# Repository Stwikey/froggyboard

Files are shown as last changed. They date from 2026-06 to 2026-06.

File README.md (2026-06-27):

# Keroppi
Screenshot 2026-06-21 at 12 25 49 AM

A cozy keyboard with every add-on you can think of! Keroppi is a wired keyboard, powered by a Raspberry Pi Pico through a modern USB-C port. It resembles a 75% keyboard layout style with 79 keys and also features a rotary encoder that can be used to toggle many short cuts such as turning the volume up or down. It also acts as another switch! There is also a TFT LCD screen that can display all sorts of images as you type! Finally, Keroppi has per key RGB lighting, and plays cool lighting animations on the keyboard!

# What does Keroppi do?

Keroppi is a wired keyboard that can be connected to your computer so you can start typing comfortably! it comes with cool components such as per-key RGB backlighting that plays animations as you type, a rotary encoder, and a TFT LCD screen that can display cool images or animations! Keroppi was designed to be an "all in one" keyboard, at least it's everything that I would want in a keyboard :D

# Why does Keroppi exist?

I've never owned a keyboard before despite being on my computer all day so I thought this was the perfect time to make one from scratch! Plus I'd be able to add as many features as I want and completely personalize it :D

# How do you use Keroppi?

## Assembly Instructions

#### 1. Handsoldering the PCB

Start by assembling the PCB! Handsolder all of the components onto the the PCB board according to the silkscreen diagram, that includes any LEDs, capacitors, resistors, pin headers, Raspberry Pi Pico, USB-C, TFT LCD, rotary encoder, and hotswap sockets.

The bottom should look something like this

Screenshot 2026-06-26 at 2 46 52 AM

The top should look something like this 

Screenshot 2026-06-26 at 2 46 19 AM

#### 1.5. Soldering the Data Lines

Twist two jumper wires together, trying to keep them the same length. Solder one of the jumper wires from TP2 on the Raspberry Pi Pico to D- and a jumper wire from TP3 on the Raspberry Pi Pico to D+ to connect the data lines.

Please note that although this method can work, it is still risky as data may not be able to establish a reliable connection. If this happens and you see data is not being transferred well, you can simply just use the usb port instead of the usb-c port.

#### 2. Assembling the Switch Plate

Assemble the switch plate by sliding in the stabilizers to their respective mounts

Screenshot 2026-06-22 at 5 50 42 PM

#### 3. Attach the Base

Install M2 female–male hex spacers in the base mounting holes and space out the switch plate from the PCB using 4mm spacers, next screw the layers in using a M2 screws inserted from the switch plate

Screenshot 2026-06-22 at 5 55 56 PM
Screenshot 2026-06-22 at 5 55 36 PM

#### 4. Attach the top plate

Slide in the top plate and it should hold screwless using friction! 

Screenshot 2026-06-22 at 5 57 17 PM

#### 5. Insert the switches

You can now insert the switches through the hotswap sockets

Screenshot 2026-06-22 at 6 00 36 PM

#### 6. Attach the keycaps

Attach the keycaps onto the switches

Screenshot 2026-06-22 at 6 01 44 PM

#### 7. Flashing Firmware

Simply start by putting the Raspberry Pi Pico into bootloader mode by plugging it into a USB port and pressing down the BOOTSEL button, once you see RPI-RPI2 open on your computer, drag the frogboard_default.uf2 file onto it (found in the firmware folder of this github repository) and you are ready to start typing!

Screenshot 2026-06-23 at 5 28 59 PM

# Schematic

## Switch Matrix

Screenshot 2026-06-21 at 12 45 51 AM

## RGB Daisy Chain

Screenshot 2026-06-21 at 12 46 11 AM

## Other Components

Screenshot 2026-06-21 at 1 07 53 AM

# PCB

Screenshot 2026-06-25 at 11 18 47 PM

## 3D Viewer Front

Screenshot 2026-06-25 at 11 19 03 PM

## 3D Viewer Back

Screenshot 2026-06-25 at 11 19 16 PM

# 3D Model

Screenshot 2026-06-21 at 12 53 49 AM

Screenshot 2026-06-21 at 12 56 28 AM

# BOM

|Item |Qty Required|Qty*|Unit Price(CAD)|Total Price(CAD)**|URL |
|---|---|----|---|---|---|
|Keyboard PCB |1 |5 |8.64 |43.18 |https://cart.jlcpcb.com/quote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 |
|SK6812 MINI-E |80 |100 |0.07 |7.25 |https://www.aliexpress.com/item/1005005186515165.html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 |
|Kailh Hot-swappable Sockets |80 |90  |0.23 |21.13 |https://www.aliexpress.com/item/1005002240956679.html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 |
|Gateron Clear Yellow MX Switches |80 |90  |0.4 |36.4 |https://www.aliexpress.com/item/1005006376024657.html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 |
|Green PBT Keycaps Cherry Profile |80 |1 |41.48 |41.48 |https://www.aliexpress.com/item/1005011698106230.html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 |
|Raspberry Pi Pico |1 |1 |9.61 |9.61 |https://www.aliexpress.com/item/1005008488567735.html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|
|Pin Header Kit for Raspberry Pi Pico |1 |1 |4.34 |4.34 |https://www.aliexpress.com/item/1005011890511721.html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 |
|Plate-Mounted Stabilizers (4x2u 1x6.25u)|1 |1 |13.53 |13.53 |https://www.aliexpress.com/item/1005001840872635.html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 |
|Rotary Encoder Knob |1 |1 |3.73 |3.73 |https://www.aliexpress.com/item/1005008610645902.html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 |
|EC11 Rotary Encoder Plum Axis |1 |5 |16.37 |16.37 |https://www.aliexpress.com/item/1005011653314162.html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 |
|0805 SMD Resistor 130Ω |1 |100 |0.1 |9.52 |https://www.aliexpress.com/item/1005011924238866.html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 |
|0.96 ST7735 LCD |1 |1 |11.26 |11.26 |https://www.lcsc.com/product-detail/C18198246.html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 |
|NMOS Transistor SOT-23 |1 |10  |0.86 |8.63 |https://www.aliexpress.com/item/1005009954469992.html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 |
|08.05 SMD Resistor 5.1k |2 |100 |0.1 |9.52 |https://www.aliexpress.com/item/1005011924238866.html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 |
|THT USB-C |1 |1 |10.45 |10.45 |https://www.lcsc.com/cart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 |
|0805 SMD Resistor 500Ω |3 |100 |0.1 |9.52 |https://www.aliexpress.com/item/1005011924238866.html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 |
|THT White 5mm LED |1 |1 |8.47 |8.47 |https://www.digikey.ca/en/products/detail/cree-led/C513A-WSN-CY0Z0231/5120059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 |
|100nF Ceramic Capacitor SMD |80 |100 |0.03 |2.83 |https://www.aliexpress.com/item/1005007175952826.html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 |
|16mm M2 Screws |15 |482 |0.03 |9.65 |https://www.aliexpress.com/item/1005005546734247.html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 |
|4mm M2 Spacer |15 |20  |0.4 |7.94 |https://www.aliexpress.com/item/1005008727558165.html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 |
|M2 x 4mm Standoffs |15 |30  |0.39 |11.68 |https://www.aliexpress.com/item/1005011821593023.html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 |
|Top Plate |1 |1 |0 |0 |3D Printed |
|Bottom Base |1 |1 |0 |0 |3D Printed |
|Switch Plate |1 |1 |0 |0 |3D Printed |
|Jumper Wires |1 |1 |14.91 |14.91 |https://www.aliexpress.com/item/1005006996255957.html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 |
|Total | | | |311.4 | |

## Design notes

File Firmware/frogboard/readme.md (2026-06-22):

# frogboard

firmware for a 80 key wired keyboard with a rotary encoder, tft lcd, and per key rgb backlighting

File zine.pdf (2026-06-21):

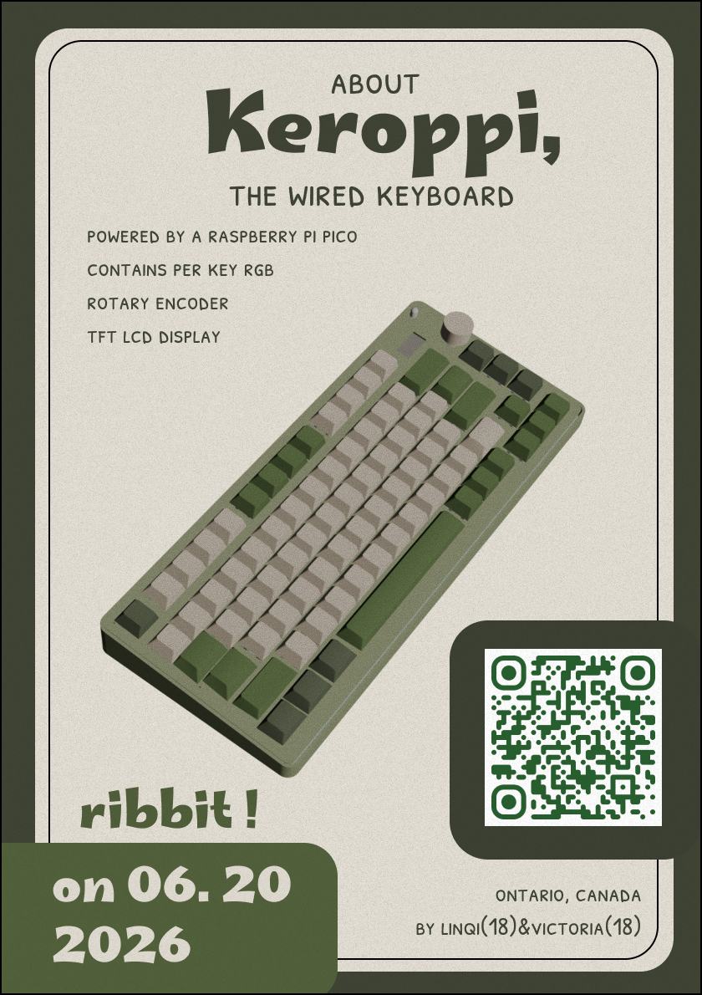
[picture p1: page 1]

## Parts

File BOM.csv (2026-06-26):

Item | Qty Required | Qty* | Unit Price(CAD) | Total Price(CAD)** | URL
Keyboard PCB | 1 | 5 | 8.64 | 43.18 | https://cart.jlcpcb.com/quote?stencilLayer=2&stencilWidth=100&stencilLength=100&stencilCounts=5&plateType=1
SK6812 MINI-E | 80 | 100 | 0.07 | 7.25 | https://www.aliexpress.com/item/1005005186515165.html?mp=1
Kailh Hot-swappable Sockets | 80 | 90 | 0.23 | 21.13 | https://www.aliexpress.com/item/1005002240956679.html?mp=1
Gateron Clear Yellow MX Switches | 80 | 90 | 0.4 | 36.4 | https://www.aliexpress.com/item/1005006376024657.html?mp=1
Green PBT Keycaps Cherry Profile | 80 | 1 | 41.48 | 41.48 | https://www.aliexpress.com/item/1005011698106230.html?curPageLogUid=LUT1sxCeVqjB
Raspberry Pi Pico | 1 | 1 | 9.61 | 9.61 | https://www.aliexpress.com/item/1005008488567735.html?curPageLogUid=FYVvLIyyXM7I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
Pin Header Kit for Raspberry Pi Pico | 1 | 1 | 4.34 | 4.34 | https://www.aliexpress.com/item/1005011890511721.html?curPageLogUid=W7DVBS57MRTf
Plate-Mounted Stabilizers (4x2u 1x6.25u) | 1 | 1 | 13.53 | 13.53 | https://www.aliexpress.com/item/1005001840872635.html?curPageLogUid=Rhk2c3Va2c9G
Rotary Encoder Knob | 1 | 1 | 3.73 | 3.73 | https://www.aliexpress.com/item/1005008610645902.html?curPageLogUid=fTDSHgs01fhl
EC11 Rotary Encoder Plum Axis | 1 | 5 | 16.37 | 16.37 | https://www.aliexpress.com/item/1005011653314162.html?curPageLogUid=7R8KvrnWqpem
0805 SMD Resistor 130Ω | 1 | 100 | 0.1 | 9.52 | https://www.aliexpress.com/item/1005011924238866.html?curPageLogUid=iQ7173pnNOWj
0.96 ST7735 LCD | 1 | 1 | 11.26 | 11.26 | https://www.lcsc.com/product-detail/C18198246.html?s_z=s_p_HS096T01H13
NMOS Transistor SOT-23 | 1 | 10 | 0.86 | 8.63 | https://www.aliexpress.com/item/1005009954469992.html?curPageLogUid=NSzXLXIYyNRr
08.05 SMD Resistor 5.1k | 2 | 100 | 0.1 | 9.52 | https://www.aliexpress.com/item/1005011924238866.html?curPageLogUid=iQ7173pnNOWj
THT USB-C | 1 | 1 | 10.45 | 10.45 | https://www.lcsc.com/cart
0805 SMD Resistor 500Ω | 3 | 100 | 0.1 | 9.52 | https://www.aliexpress.com/item/1005011924238866.html?curPageLogUid=iQ7173pnNOWj
THT White 5mm LED | 1 | 1 | 8.47 | 8.47 | https://www.digikey.ca/en/products/detail/cree-led/C513A-WSN-CY0Z0231/5120059?gclsrc=aw.ds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
100nF Ceramic Capacitor SMD | 80 | 100 | 0.03 | 2.83 | https://www.aliexpress.com/item/1005007175952826.html?curPageLogUid=eDKNDKFdjuH1
16mm M2 Screws | 15 | 482 | 0.03 | 9.65 | https://www.aliexpress.com/item/1005005546734247.html?curPageLogUid=qlXc2mG4YVQw
4mm M2 Spacer | 15 | 20 | 0.4 | 7.94 | https://www.aliexpress.com/item/1005008727558165.html?curPageLogUid=TCVVRVc2M5ED
M2 x 4mm Standoffs | 15 | 30 | 0.39 | 11.68 | https://www.aliexpress.com/item/1005011821593023.html
Top Plate | 1 | 1 | 0 | 0 | 3D Printed
Bottom Base | 1 | 1 | 0 | 0 | 3D Printed
Switch Plate | 1 | 1 | 0 | 0 | 3D Printed
Jumper Wires | 1 | 1 | 14.91 | 14.91 | https://www.aliexpress.com/item/1005006996255957.html?curPageLogUid=Fk1rRQPMAnsz
Total |  |  |  | 311.4

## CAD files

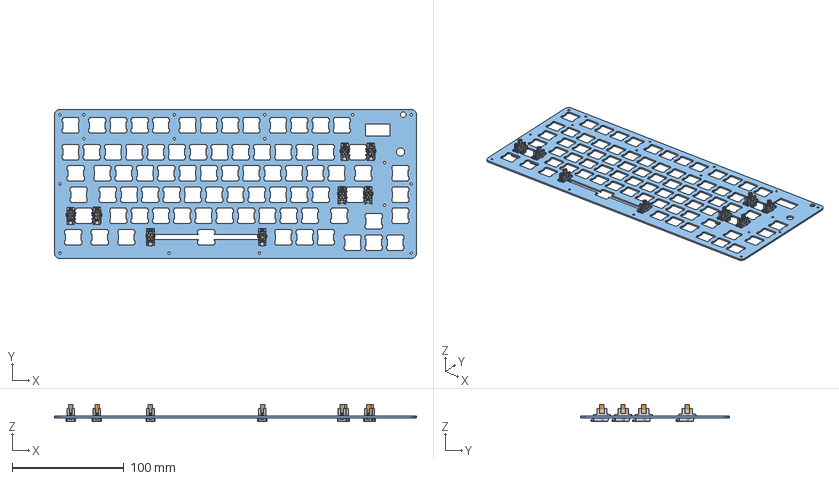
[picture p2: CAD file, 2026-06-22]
CAD/STEP Files/Switch Plate Assembled.step
324.0 x 133.5 x 15.3 mm

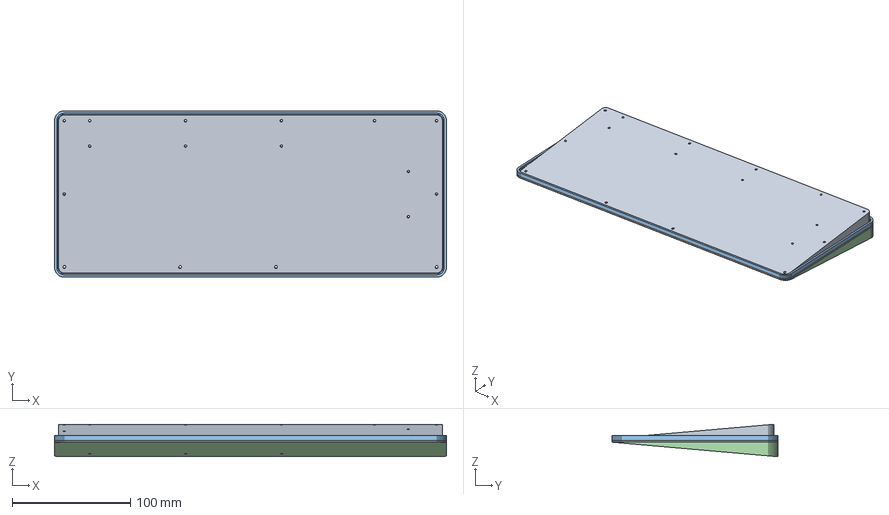
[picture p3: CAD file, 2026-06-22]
CAD/Base.step
331.0 x 140.5 x 27.4 mm

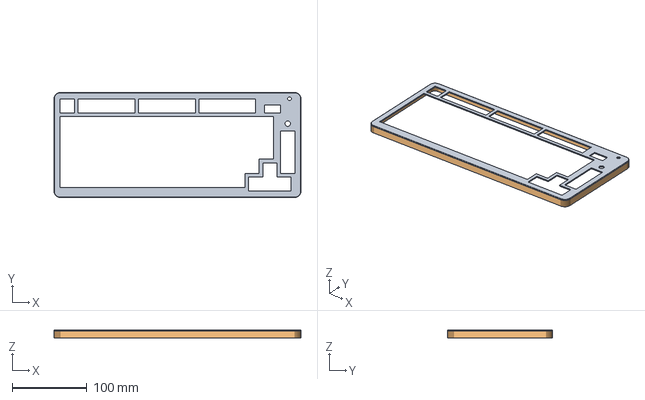
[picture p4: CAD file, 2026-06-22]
CAD/STEP Files/Top Plate.step
331.0 x 140.5 x 11.1 mm

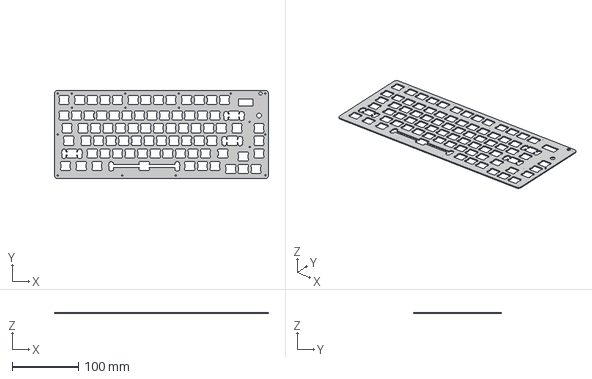
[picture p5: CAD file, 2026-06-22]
CAD/STEP Files/Switch Plate.step
324.0 x 133.5 x 1.50 mm

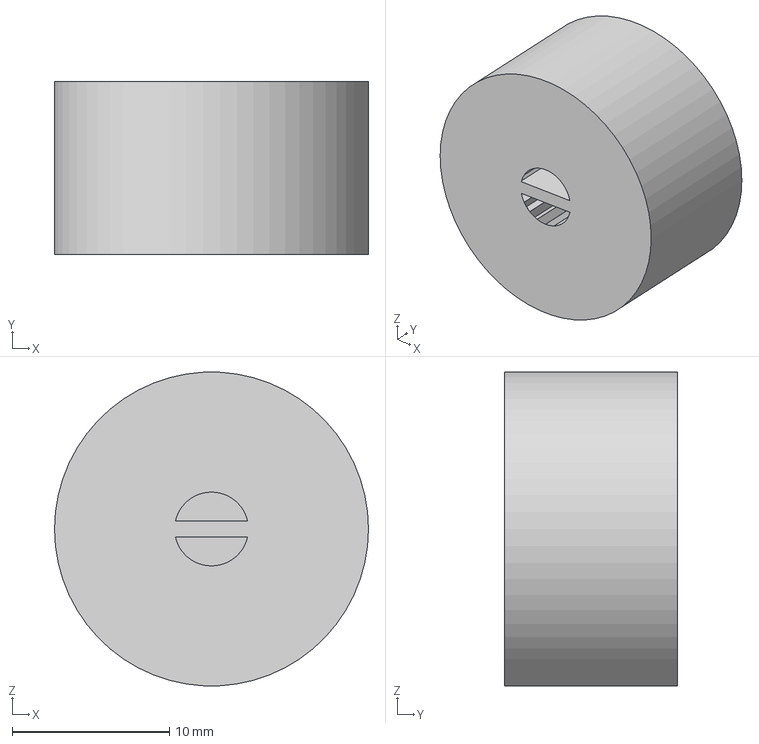
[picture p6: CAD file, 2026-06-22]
CAD/STEP Files/Rotary Encoder Cap.step
20.0 x 11.0 x 20.0 mm

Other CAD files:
CAD/Fusion Source Files/Switch Plate Assembled.f3z
CAD/Fusion Source Files/Switch Plate.f3d
CAD/Fusion Source Files/Top Plate.f3d

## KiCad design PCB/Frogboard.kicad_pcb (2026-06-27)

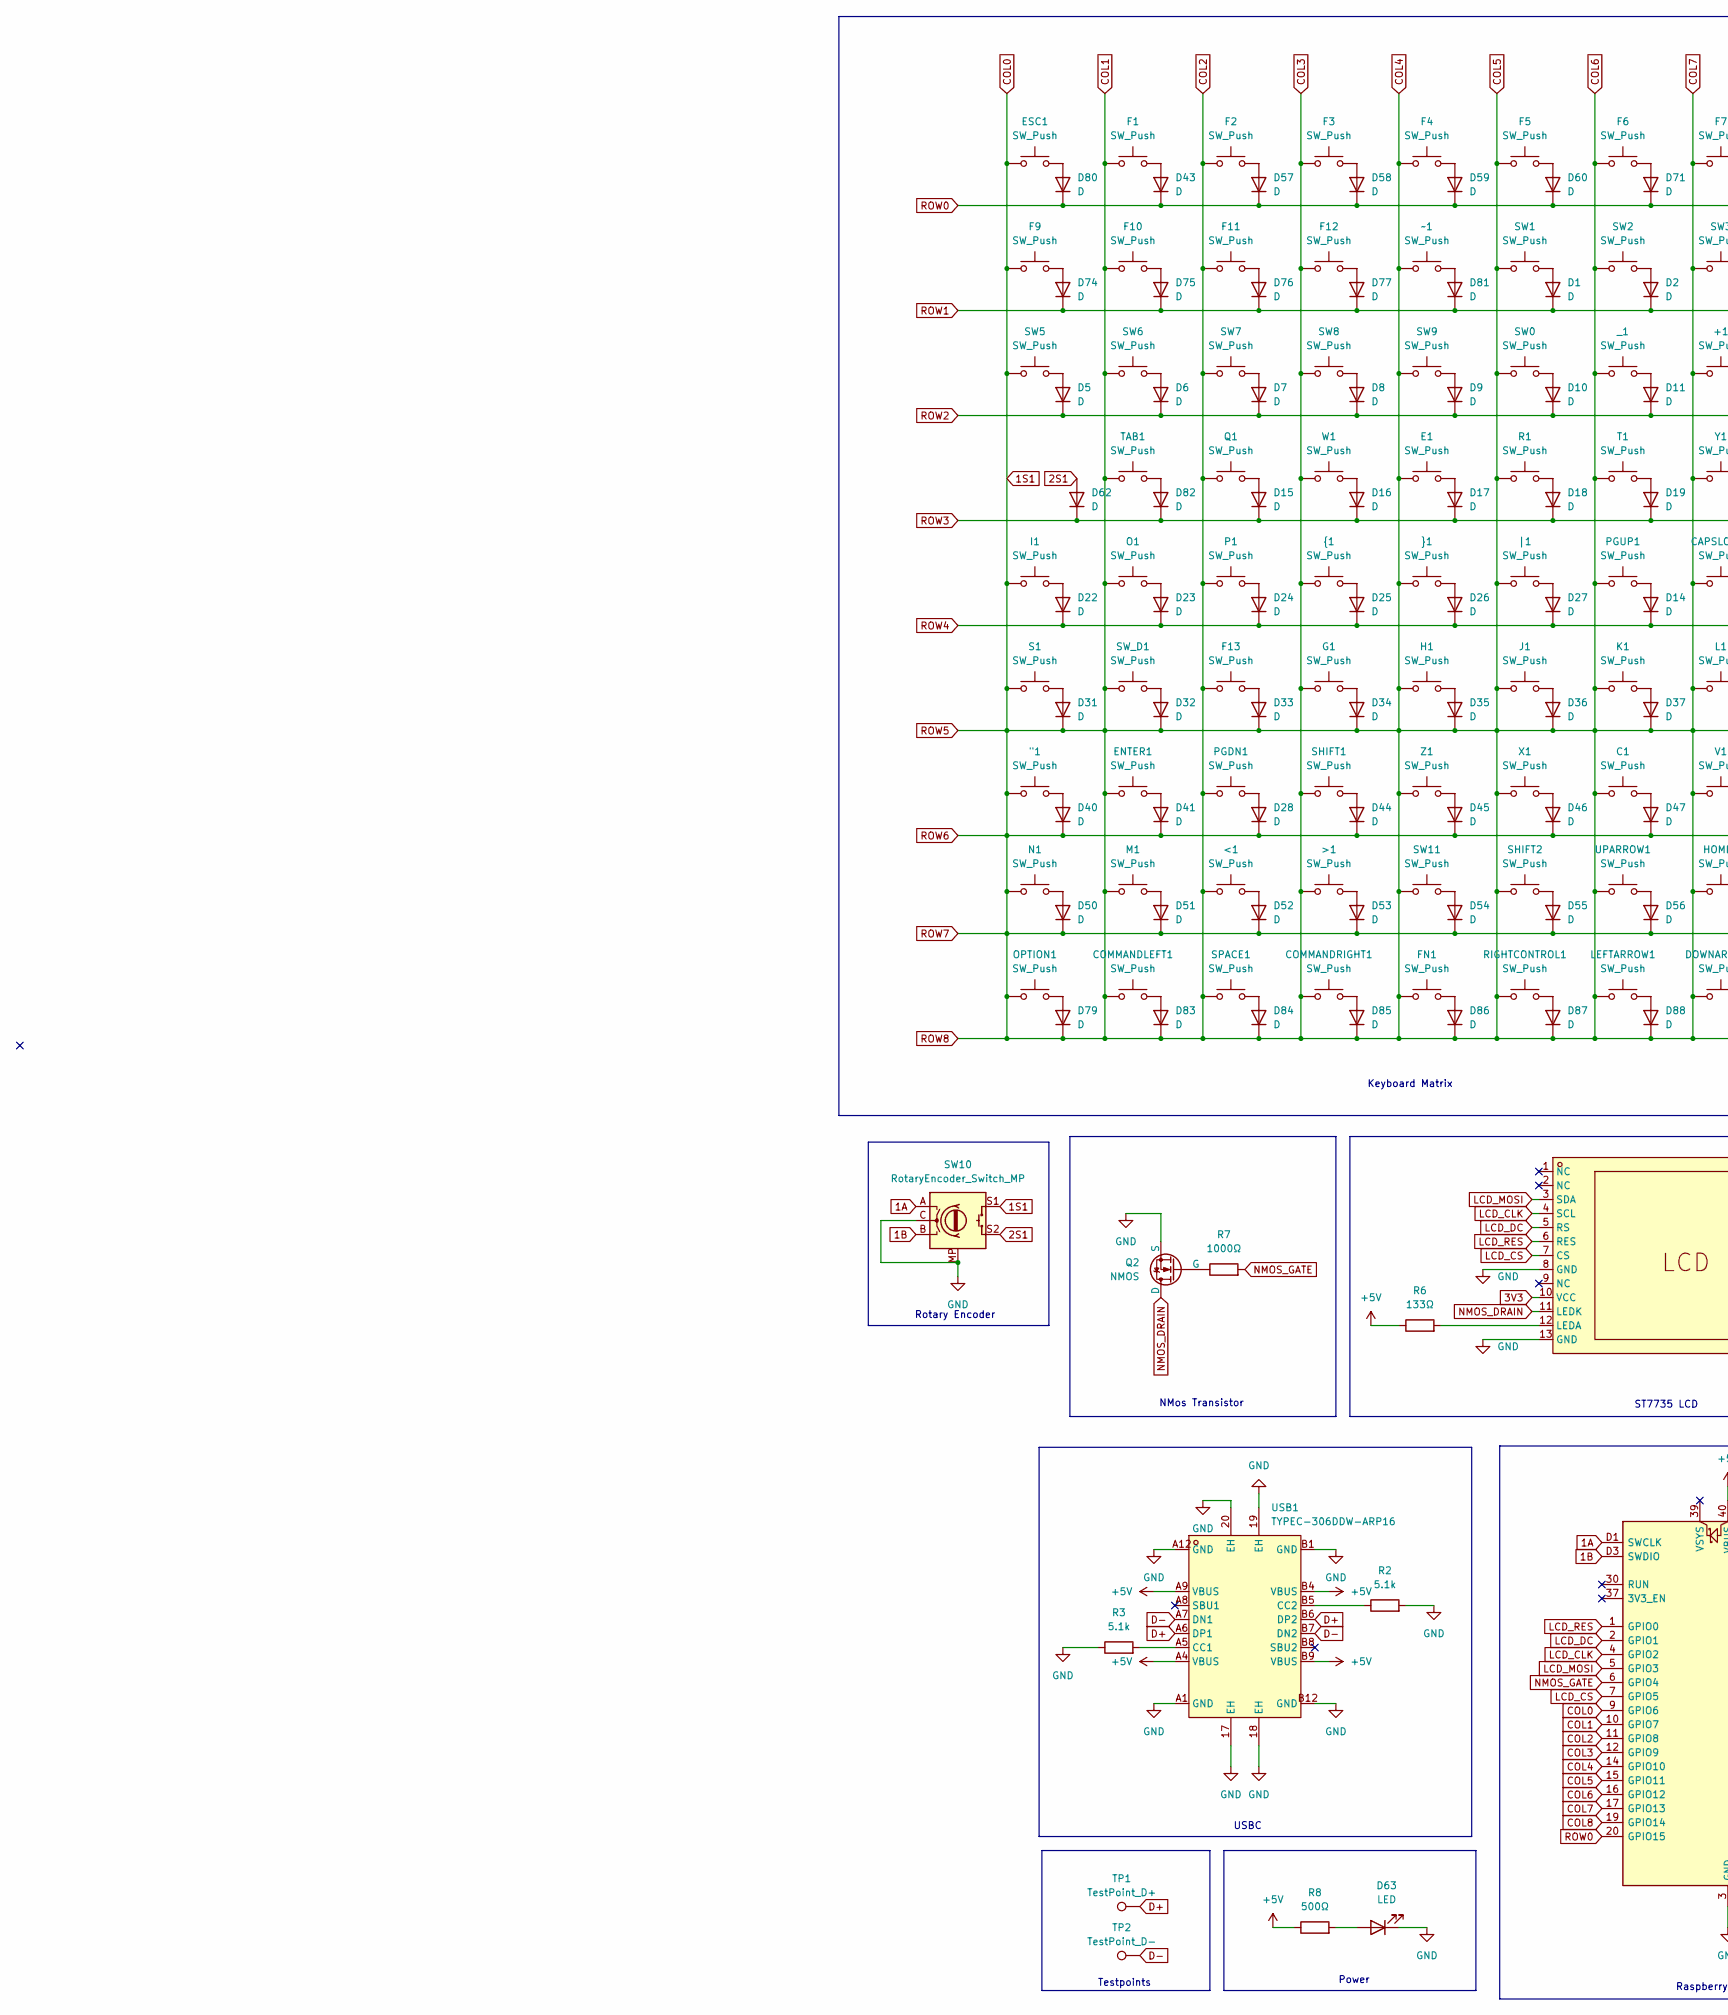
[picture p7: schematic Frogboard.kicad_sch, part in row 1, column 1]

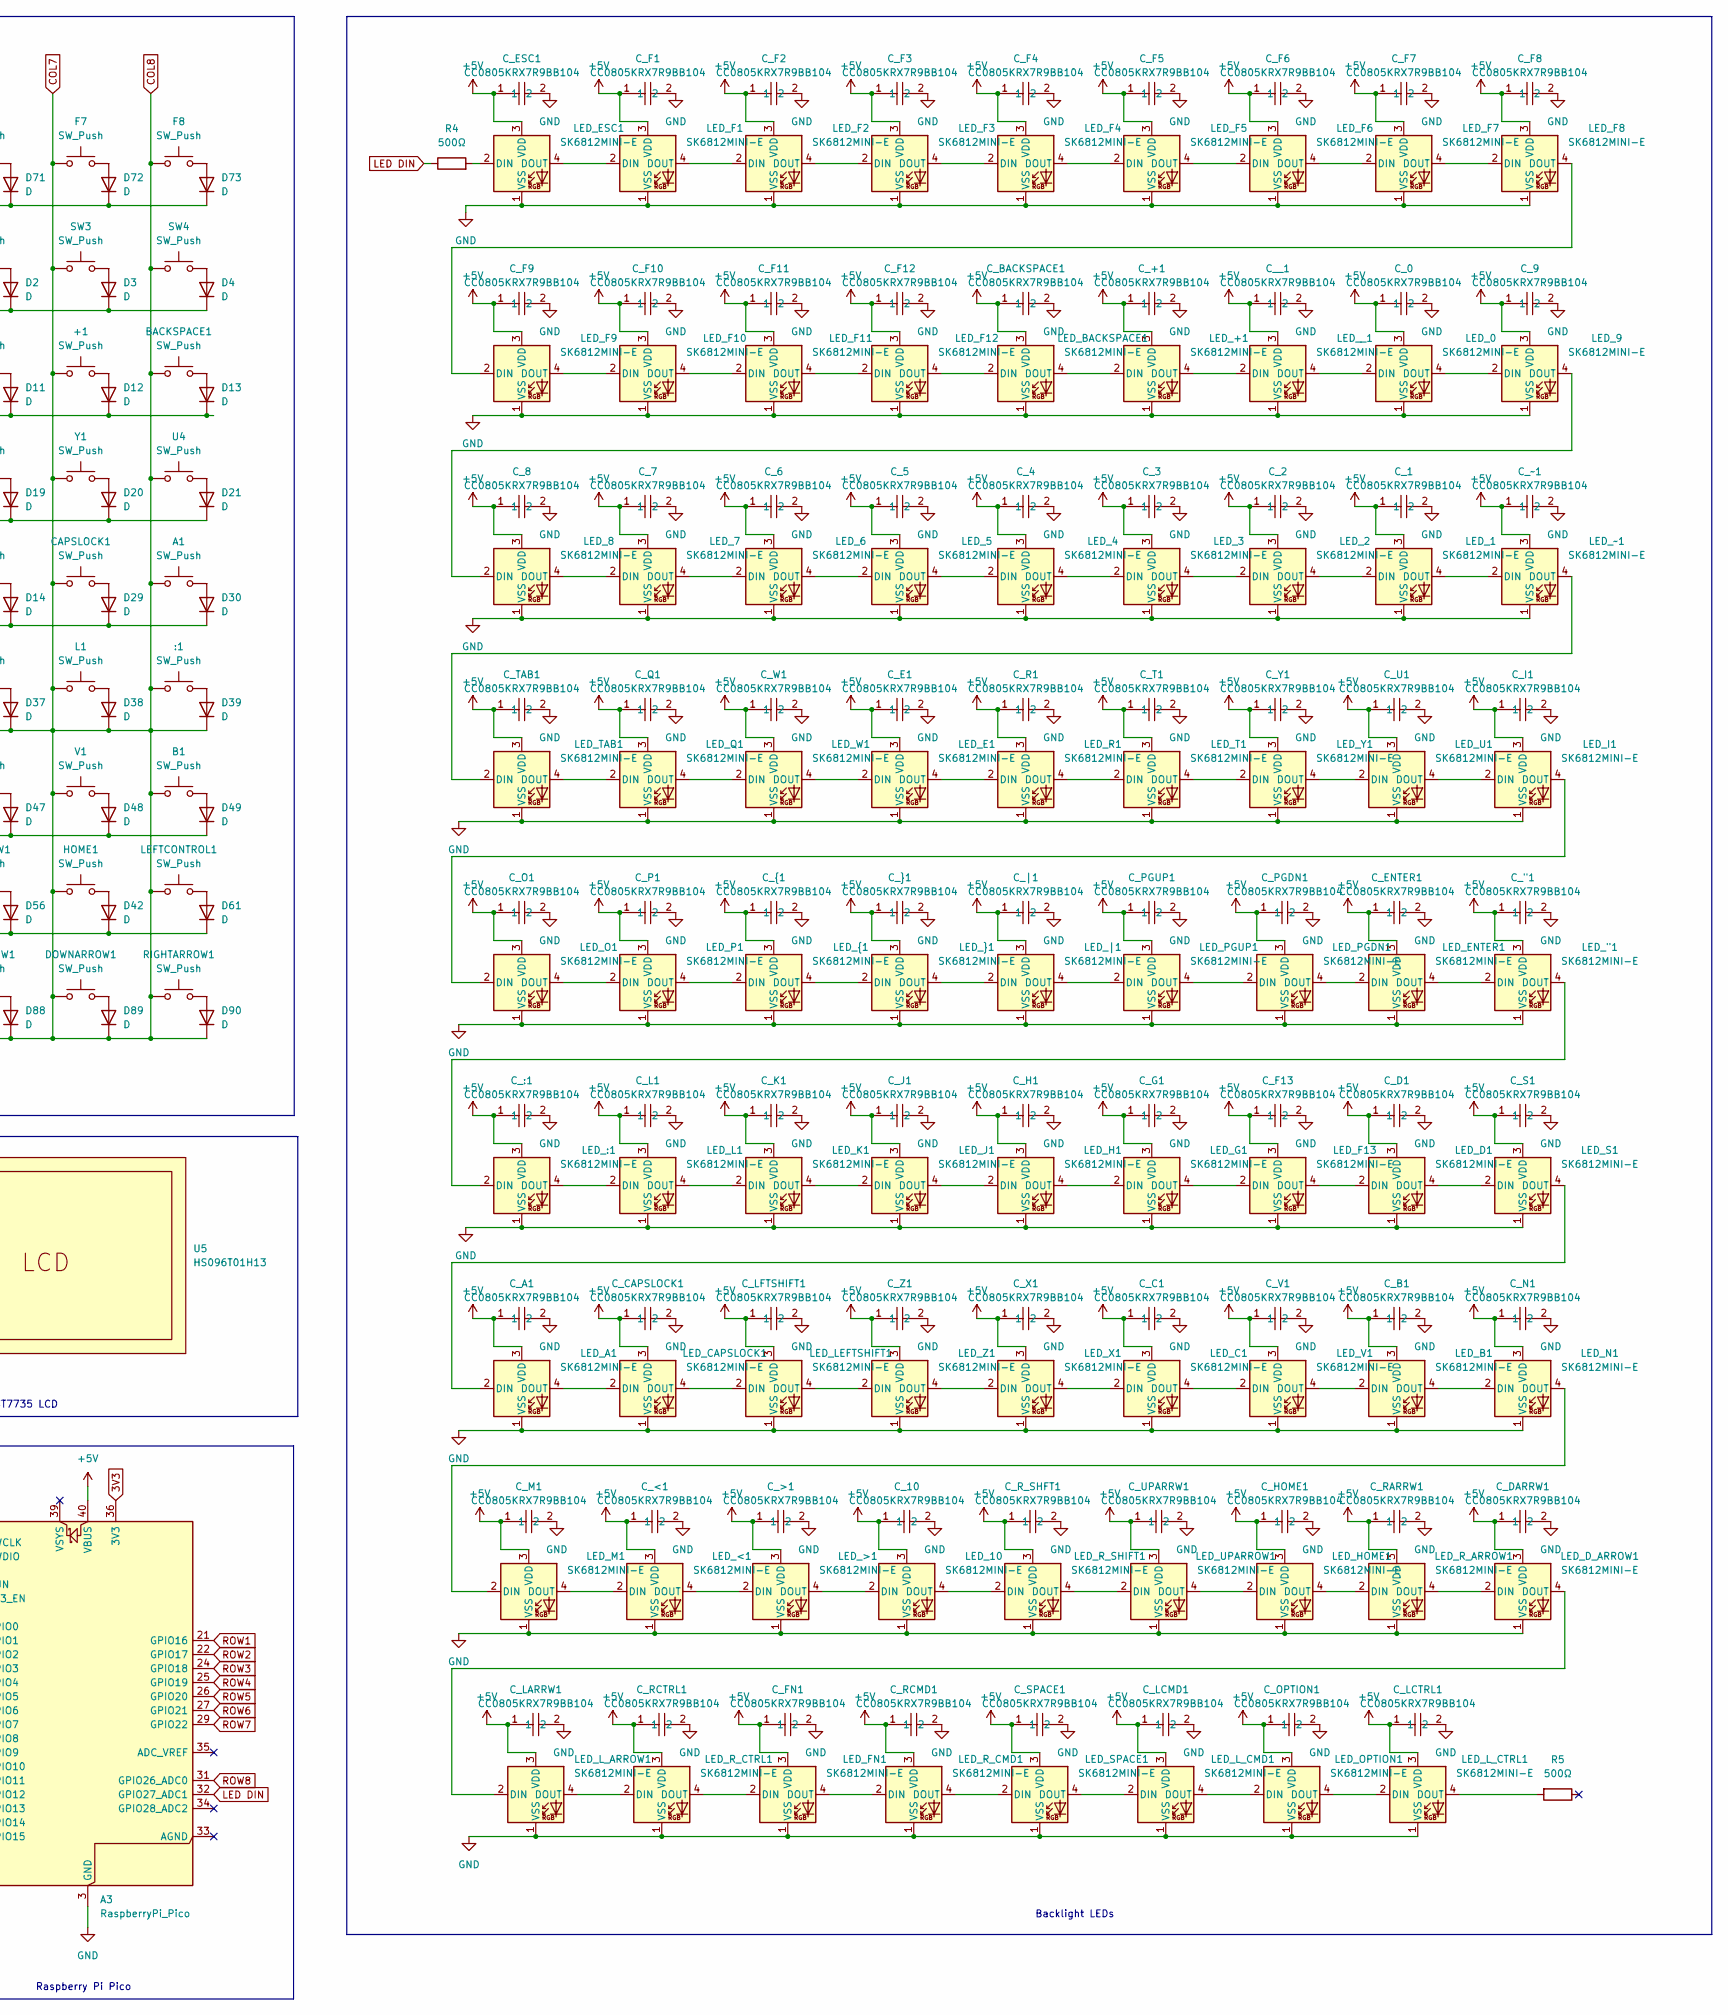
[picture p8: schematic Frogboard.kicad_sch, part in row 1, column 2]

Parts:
"1: SW_Push; SW_MX_HS_CPG151101S11_1u
+1: SW_Push; SW_MX_HS_CPG151101S11_1u
:1: SW_Push; SW_MX_HS_CPG151101S11_1u
<1: SW_Push; SW_MX_HS_CPG151101S11_1u
>1: SW_Push; SW_MX_HS_CPG151101S11_1u
A1: SW_Push; SW_MX_HS_CPG151101S11_1u
A3: RaspberryPi_Pico; RaspberryPi_Pico_SMD_HandSolder
B1: SW_Push; SW_MX_HS_CPG151101S11_1u
BACKSPACE1: SW_Push; SW_MX_HS_CPG151101S11_1u
C1: SW_Push; SW_MX_HS_CPG151101S11_1u
CAPSLOCK1: SW_Push; SW_MX_HS_CPG151101S11_1.75u
COMMANDLEFT1: SW_Push; SW_MX_HS_CPG151101S11_1.25u
COMMANDRIGHT1: SW_Push; SW_MX_HS_CPG151101S11_1u
C_0, C_1, C_2, C_3, C_4, C_5, C_6, C_7, C_8, C_9, C_10: CC0805KRX7R9BB104; C_0805_2012Metric_Pad1.18x1.45mm_HandSolder; MPN CC0805KRX7R9BB104; LCSC Part C49678
C_"1: CC0805KRX7R9BB104; C_0805_2012Metric_Pad1.18x1.45mm_HandSolder; MPN CC0805KRX7R9BB104; LCSC Part C49678
C_+1: CC0805KRX7R9BB104; C_0805_2012Metric_Pad1.18x1.45mm_HandSolder; MPN CC0805KRX7R9BB104; LCSC Part C49678
C_:1: CC0805KRX7R9BB104; C_0805_2012Metric_Pad1.18x1.45mm_HandSolder; MPN CC0805KRX7R9BB104; LCSC Part C49678
C_<1: CC0805KRX7R9BB104; C_0805_2012Metric_Pad1.18x1.45mm_HandSolder; MPN CC0805KRX7R9BB104; LCSC Part C49678
C_>1: CC0805KRX7R9BB104; C_0805_2012Metric_Pad1.18x1.45mm_HandSolder; MPN CC0805KRX7R9BB104; LCSC Part C49678
C_A1: CC0805KRX7R9BB104; C_0805_2012Metric_Pad1.18x1.45mm_HandSolder; MPN CC0805KRX7R9BB104; LCSC Part C49678
C_B1: CC0805KRX7R9BB104; C_0805_2012Metric_Pad1.18x1.45mm_HandSolder; MPN CC0805KRX7R9BB104; LCSC Part C49678
C_BACKSPACE1: CC0805KRX7R9BB104; C_0805_2012Metric_Pad1.18x1.45mm_HandSolder; MPN CC0805KRX7R9BB104; LCSC Part C49678
C_C1: CC0805KRX7R9BB104; C_0805_2012Metric_Pad1.18x1.45mm_HandSolder; MPN CC0805KRX7R9BB104; LCSC Part C49678
C_CAPSLOCK1: CC0805KRX7R9BB104; C_0805_2012Metric_Pad1.18x1.45mm_HandSolder; MPN CC0805KRX7R9BB104; LCSC Part C49678
C_D1: CC0805KRX7R9BB104; C_0805_2012Metric_Pad1.18x1.45mm_HandSolder; MPN CC0805KRX7R9BB104; LCSC Part C49678
C_DARRW1: CC0805KRX7R9BB104; C_0805_2012Metric_Pad1.18x1.45mm_HandSolder; MPN CC0805KRX7R9BB104; LCSC Part C49678
C_E1: CC0805KRX7R9BB104; C_0805_2012Metric_Pad1.18x1.45mm_HandSolder; MPN CC0805KRX7R9BB104; LCSC Part C49678
C_ENTER1: CC0805KRX7R9BB104; C_0805_2012Metric_Pad1.18x1.45mm_HandSolder; MPN CC0805KRX7R9BB104; LCSC Part C49678
C_ESC1: CC0805KRX7R9BB104; C_0805_2012Metric_Pad1.18x1.45mm_HandSolder; MPN CC0805KRX7R9BB104; LCSC Part C49678
C_F1, C_F2, C_F3, C_F4, C_F5, C_F6, C_F7, C_F8, C_F9, C_F10, C_F11, C_F12, C_F13: CC0805KRX7R9BB104; C_0805_2012Metric_Pad1.18x1.45mm_HandSolder; MPN CC0805KRX7R9BB104; LCSC Part C49678
C_FN1: CC0805KRX7R9BB104; C_0805_2012Metric_Pad1.18x1.45mm_HandSolder; MPN CC0805KRX7R9BB104; LCSC Part C49678
C_G1: CC0805KRX7R9BB104; C_0805_2012Metric_Pad1.18x1.45mm_HandSolder; MPN CC0805KRX7R9BB104; LCSC Part C49678
C_H1: CC0805KRX7R9BB104; C_0805_2012Metric_Pad1.18x1.45mm_HandSolder; MPN CC0805KRX7R9BB104; LCSC Part C49678
C_HOME1: CC0805KRX7R9BB104; C_0805_2012Metric_Pad1.18x1.45mm_HandSolder; MPN CC0805KRX7R9BB104; LCSC Part C49678
C_I1: CC0805KRX7R9BB104; C_0805_2012Metric_Pad1.18x1.45mm_HandSolder; MPN CC0805KRX7R9BB104; LCSC Part C49678
C_J1: CC0805KRX7R9BB104; C_0805_2012Metric_Pad1.18x1.45mm_HandSolder; MPN CC0805KRX7R9BB104; LCSC Part C49678
C_K1: CC0805KRX7R9BB104; C_0805_2012Metric_Pad1.18x1.45mm_HandSolder; MPN CC0805KRX7R9BB104; LCSC Part C49678
C_L1: CC0805KRX7R9BB104; C_0805_2012Metric_Pad1.18x1.45mm_HandSolder; MPN CC0805KRX7R9BB104; LCSC Part C49678
C_LARRW1: CC0805KRX7R9BB104; C_0805_2012Metric_Pad1.18x1.45mm_HandSolder; MPN CC0805KRX7R9BB104; LCSC Part C49678
C_LCMD1: CC0805KRX7R9BB104; C_0805_2012Metric_Pad1.18x1.45mm_HandSolder; MPN CC0805KRX7R9BB104; LCSC Part C49678
C_LCTRL1: CC0805KRX7R9BB104; C_0805_2012Metric_Pad1.18x1.45mm_HandSolder; MPN CC0805KRX7R9BB104; LCSC Part C49678
C_LFTSHIFT1: CC0805KRX7R9BB104; C_0805_2012Metric_Pad1.18x1.45mm_HandSolder; MPN CC0805KRX7R9BB104; LCSC Part C49678
C_M1: CC0805KRX7R9BB104; C_0805_2012Metric_Pad1.18x1.45mm_HandSolder; MPN CC0805KRX7R9BB104; LCSC Part C49678
C_N1: CC0805KRX7R9BB104; C_0805_2012Metric_Pad1.18x1.45mm_HandSolder; MPN CC0805KRX7R9BB104; LCSC Part C49678
C_O1: CC0805KRX7R9BB104; C_0805_2012Metric_Pad1.18x1.45mm_HandSolder; MPN CC0805KRX7R9BB104; LCSC Part C49678
C_OPTION1: CC0805KRX7R9BB104; C_0805_2012Metric_Pad1.18x1.45mm_HandSolder; MPN CC0805KRX7R9BB104; LCSC Part C49678
C_P1: CC0805KRX7R9BB104; C_0805_2012Metric_Pad1.18x1.45mm_HandSolder; MPN CC0805KRX7R9BB104; LCSC Part C49678
C_PGDN1: CC0805KRX7R9BB104; C_0805_2012Metric_Pad1.18x1.45mm_HandSolder; MPN CC0805KRX7R9BB104; LCSC Part C49678
C_PGUP1: CC0805KRX7R9BB104; C_0805_2012Metric_Pad1.18x1.45mm_HandSolder; MPN CC0805KRX7R9BB104; LCSC Part C49678
C_Q1: CC0805KRX7R9BB104; C_0805_2012Metric_Pad1.18x1.45mm_HandSolder; MPN CC0805KRX7R9BB104; LCSC Part C49678
C_R1: CC0805KRX7R9BB104; C_0805_2012Metric_Pad1.18x1.45mm_HandSolder; MPN CC0805KRX7R9BB104; LCSC Part C49678
C_RARRW1: CC0805KRX7R9BB104; C_0805_2012Metric_Pad1.18x1.45mm_HandSolder; MPN CC0805KRX7R9BB104; LCSC Part C49678
C_RCMD1: CC0805KRX7R9BB104; C_0805_2012Metric_Pad1.18x1.45mm_HandSolder; MPN CC0805KRX7R9BB104; LCSC Part C49678
C_RCTRL1: CC0805KRX7R9BB104; C_0805_2012Metric_Pad1.18x1.45mm_HandSolder; MPN CC0805KRX7R9BB104; LCSC Part C49678
C_R_SHFT1: CC0805KRX7R9BB104; C_0805_2012Metric_Pad1.18x1.45mm_HandSolder; MPN CC0805KRX7R9BB104; LCSC Part C49678
C_S1: CC0805KRX7R9BB104; C_0805_2012Metric_Pad1.18x1.45mm_HandSolder; MPN CC0805KRX7R9BB104; LCSC Part C49678
C_SPACE1: CC0805KRX7R9BB104; C_0805_2012Metric_Pad1.18x1.45mm_HandSolder; MPN CC0805KRX7R9BB104; LCSC Part C49678
C_T1: CC0805KRX7R9BB104; C_0805_2012Metric_Pad1.18x1.45mm_HandSolder; MPN CC0805KRX7R9BB104; LCSC Part C49678
C_TAB1: CC0805KRX7R9BB104; C_0805_2012Metric_Pad1.18x1.45mm_HandSolder; MPN CC0805KRX7R9BB104; LCSC Part C49678
C_U1: CC0805KRX7R9BB104; C_0805_2012Metric_Pad1.18x1.45mm_HandSolder; MPN CC0805KRX7R9BB104; LCSC Part C49678
C_UPARRW1: CC0805KRX7R9BB104; C_0805_2012Metric_Pad1.18x1.45mm_HandSolder; MPN CC0805KRX7R9BB104; LCSC Part C49678
C_V1: CC0805KRX7R9BB104; C_0805_2012Metric_Pad1.18x1.45mm_HandSolder; MPN CC0805KRX7R9BB104; LCSC Part C49678
C_W1: CC0805KRX7R9BB104; C_0805_2012Metric_Pad1.18x1.45mm_HandSolder; MPN CC0805KRX7R9BB104; LCSC Part C49678
C_X1: CC0805KRX7R9BB104; C_0805_2012Metric_Pad1.18x1.45mm_HandSolder; MPN CC0805KRX7R9BB104; LCSC Part C49678
C_Y1: CC0805KRX7R9BB104; C_0805_2012Metric_Pad1.18x1.45mm_HandSolder; MPN CC0805KRX7R9BB104; LCSC Part C49678
C_Z1: CC0805KRX7R9BB104; C_0805_2012Metric_Pad1.18x1.45mm_HandSolder; MPN CC0805KRX7R9BB104; LCSC Part C49678
C__1: CC0805KRX7R9BB104; C_0805_2012Metric_Pad1.18x1.45mm_HandSolder; MPN CC0805KRX7R9BB104; LCSC Part C49678
C_{1: CC0805KRX7R9BB104; C_0805_2012Metric_Pad1.18x1.45mm_HandSolder; MPN CC0805KRX7R9BB104; LCSC Part C49678
C_|1: CC0805KRX7R9BB104; C_0805_2012Metric_Pad1.18x1.45mm_HandSolder; MPN CC0805KRX7R9BB104; LCSC Part C49678
C_}1: CC0805KRX7R9BB104; C_0805_2012Metric_Pad1.18x1.45mm_HandSolder; MPN CC0805KRX7R9BB104; LCSC Part C49678
C_~1: CC0805KRX7R9BB104; C_0805_2012Metric_Pad1.18x1.45mm_HandSolder; MPN CC0805KRX7R9BB104; LCSC Part C49678
D1, D2, D3, D4, D5, D6, D7, D8, D9, D10, D11, D12, D13, D14, D15, D16, D17, D18, D19, D20, D21, D22, D23, D24, D25, D26, D27, D28, D29, D30, D31, D32, D33, D34, D35, D36, D37, D38, D39, D40, D41, D42, D43, D44, D45, D46, D47, D48, D49, D50, D51, D52, D53, D54, D55, D56, D57, D58, D59, D60, D61, D62, D71, D72, D73, D74, D75, D76, D77, D79, D80, D81, D82, D83, D84, D85, D86, D87, D88, D89, D90: D; D_SOD-123
D63: LED; LED_D5.0mm
DOWNARROW1: SW_Push; SW_MX_HS_CPG151101S11_1u
E1: SW_Push; SW_MX_HS_CPG151101S11_1u
ENTER1: SW_Push; SW_MX_HS_CPG151101S11_1u
ESC1: SW_Push; SW_MX_HS_CPG151101S11_1u
F1, F2, F3, F4, F5, F6, F7, F8, F9, F10, F11, F12, F13: SW_Push; SW_MX_HS_CPG151101S11_1u
FN1: SW_Push; SW_MX_HS_CPG151101S11_1u
G1: SW_Push; SW_MX_HS_CPG151101S11_1u
H1: SW_Push; SW_MX_HS_CPG151101S11_1u
HOME1: SW_Push; SW_MX_HS_CPG151101S11_1u
I1: SW_Push; SW_MX_HS_CPG151101S11_1u
J1: SW_Push; SW_MX_HS_CPG151101S11_1u
K1: SW_Push; SW_MX_HS_CPG151101S11_1u
L1: SW_Push; SW_MX_HS_CPG151101S11_1u
LED_0, LED_1, LED_2, LED_3, LED_4, LED_5, LED_6, LED_7, LED_8, LED_9, LED_10: SK6812MINI-E; LED_SK6812MINI-E_3.2x2.8mm_P1.5mm_ReverseMount
LED_"1: SK6812MINI-E; LED_SK6812MINI-E_3.2x2.8mm_P1.5mm_ReverseMount
LED_+1: SK6812MINI-E; LED_SK6812MINI-E_3.2x2.8mm_P1.5mm_ReverseMount
LED_:1: SK6812MINI-E; LED_SK6812MINI-E_3.2x2.8mm_P1.5mm_ReverseMount
LED_<1: SK6812MINI-E; LED_SK6812MINI-E_3.2x2.8mm_P1.5mm_ReverseMount
LED_>1: SK6812MINI-E; LED_SK6812MINI-E_3.2x2.8mm_P1.5mm_ReverseMount
LED_A1: SK6812MINI-E; LED_SK6812MINI-E_3.2x2.8mm_P1.5mm_ReverseMount
LED_B1: SK6812MINI-E; LED_SK6812MINI-E_3.2x2.8mm_P1.5mm_ReverseMount
LED_BACKSPACE1: SK6812MINI-E; LED_SK6812MINI-E_3.2x2.8mm_P1.5mm_ReverseMount
LED_C1: SK6812MINI-E; LED_SK6812MINI-E_3.2x2.8mm_P1.5mm_ReverseMount
LED_CAPSLOCK1: SK6812MINI-E; LED_SK6812MINI-E_3.2x2.8mm_P1.5mm_ReverseMount
LED_D1: SK6812MINI-E; LED_SK6812MINI-E_3.2x2.8mm_P1.5mm_ReverseMount
LED_D_ARROW1: SK6812MINI-E; LED_SK6812MINI-E_3.2x2.8mm_P1.5mm_ReverseMount
LED_E1: SK6812MINI-E; LED_SK6812MINI-E_3.2x2.8mm_P1.5mm_ReverseMount
LED_ENTER1: SK6812MINI-E; LED_SK6812MINI-E_3.2x2.8mm_P1.5mm_ReverseMount
LED_ESC1: SK6812MINI-E; LED_SK6812MINI-E_3.2x2.8mm_P1.5mm_ReverseMount
LED_F1, LED_F2, LED_F3, LED_F4, LED_F5, LED_F6, LED_F7, LED_F8, LED_F9, LED_F10, LED_F11, LED_F12, LED_F13: SK6812MINI-E; LED_SK6812MINI-E_3.2x2.8mm_P1.5mm_ReverseMount
LED_FN1: SK6812MINI-E; LED_SK6812MINI-E_3.2x2.8mm_P1.5mm_ReverseMount
LED_G1: SK6812MINI-E; LED_SK6812MINI-E_3.2x2.8mm_P1.5mm_ReverseMount
LED_H1: SK6812MINI-E; LED_SK6812MINI-E_3.2x2.8mm_P1.5mm_ReverseMount
LED_HOME1: SK6812MINI-E; LED_SK6812MINI-E_3.2x2.8mm_P1.5mm_ReverseMount
LED_I1: SK6812MINI-E; LED_SK6812MINI-E_3.2x2.8mm_P1.5mm_ReverseMount
LED_J1: SK6812MINI-E; LED_SK6812MINI-E_3.2x2.8mm_P1.5mm_ReverseMount
LED_K1: SK6812MINI-E; LED_SK6812MINI-E_3.2x2.8mm_P1.5mm_ReverseMount
LED_L1: SK6812MINI-E; LED_SK6812MINI-E_3.2x2.8mm_P1.5mm_ReverseMount
LED_LEFTSHIFT1: SK6812MINI-E; LED_SK6812MINI-E_3.2x2.8mm_P1.5mm_ReverseMount
LED_L_ARROW1: SK6812MINI-E; LED_SK6812MINI-E_3.2x2.8mm_P1.5mm_ReverseMount
LED_L_CMD1: SK6812MINI-E; LED_SK6812MINI-E_3.2x2.8mm_P1.5mm_ReverseMount
LED_L_CTRL1: SK6812MINI-E; LED_SK6812MINI-E_3.2x2.8mm_P1.5mm_ReverseMount
LED_M1: SK6812MINI-E; LED_SK6812MINI-E_3.2x2.8mm_P1.5mm_ReverseMount
LED_N1: SK6812MINI-E; LED_SK6812MINI-E_3.2x2.8mm_P1.5mm_ReverseMount
LED_O1: SK6812MINI-E; LED_SK6812MINI-E_3.2x2.8mm_P1.5mm_ReverseMount
LED_OPTION1: SK6812MINI-E; LED_SK6812MINI-E_3.2x2.8mm_P1.5mm_ReverseMount
LED_P1: SK6812MINI-E; LED_SK6812MINI-E_3.2x2.8mm_P1.5mm_ReverseMount
LED_PGDN1: SK6812MINI-E; LED_SK6812MINI-E_3.2x2.8mm_P1.5mm_ReverseMount
LED_PGUP1: SK6812MINI-E; LED_SK6812MINI-E_3.2x2.8mm_P1.5mm_ReverseMount
LED_Q1: SK6812MINI-E; LED_SK6812MINI-E_3.2x2.8mm_P1.5mm_ReverseMount
LED_R1: SK6812MINI-E; LED_SK6812MINI-E_3.2x2.8mm_P1.5mm_ReverseMount
LED_R_ARROW1: SK6812MINI-E; LED_SK6812MINI-E_3.2x2.8mm_P1.5mm_ReverseMount
LED_R_CMD1: SK6812MINI-E; LED_SK6812MINI-E_3.2x2.8mm_P1.5mm_ReverseMount
LED_R_CTRL1: SK6812MINI-E; LED_SK6812MINI-E_3.2x2.8mm_P1.5mm_ReverseMount
LED_R_SHIFT1: SK6812MINI-E; LED_SK6812MINI-E_3.2x2.8mm_P1.5mm_ReverseMount
LED_S1: SK6812MINI-E; LED_SK6812MINI-E_3.2x2.8mm_P1.5mm_ReverseMount
LED_SPACE1: SK6812MINI-E; LED_SK6812MINI-E_3.2x2.8mm_P1.5mm_ReverseMount
LED_T1: SK6812MINI-E; LED_SK6812MINI-E_3.2x2.8mm_P1.5mm_ReverseMount
LED_TAB1: SK6812MINI-E; LED_SK6812MINI-E_3.2x2.8mm_P1.5mm_ReverseMount
LED_U1: SK6812MINI-E; LED_SK6812MINI-E_3.2x2.8mm_P1.5mm_ReverseMount
LED_UPARROW1: SK6812MINI-E; LED_SK6812MINI-E_3.2x2.8mm_P1.5mm_ReverseMount
LED_V1: SK6812MINI-E; LED_SK6812MINI-E_3.2x2.8mm_P1.5mm_ReverseMount
LED_W1: SK6812MINI-E; LED_SK6812MINI-E_3.2x2.8mm_P1.5mm_ReverseMount
LED_X1: SK6812MINI-E; LED_SK6812MINI-E_3.2x2.8mm_P1.5mm_ReverseMount
LED_Y1: SK6812MINI-E; LED_SK6812MINI-E_3.2x2.8mm_P1.5mm_ReverseMount
LED_Z1: SK6812MINI-E; LED_SK6812MINI-E_3.2x2.8mm_P1.5mm_ReverseMount
LED__1: SK6812MINI-E; LED_SK6812MINI-E_3.2x2.8mm_P1.5mm_ReverseMount
LED_{1: SK6812MINI-E; LED_SK6812MINI-E_3.2x2.8mm_P1.5mm_ReverseMount
LED_|1: SK6812MINI-E; LED_SK6812MINI-E_3.2x2.8mm_P1.5mm_ReverseMount
LED_}1: SK6812MINI-E; LED_SK6812MINI-E_3.2x2.8mm_P1.5mm_ReverseMount
LED_~1: SK6812MINI-E; LED_SK6812MINI-E_3.2x2.8mm_P1.5mm_ReverseMount
LEFTARROW1: SW_Push; SW_MX_HS_CPG151101S11_1u
LEFTCONTROL1: SW_Push; SW_MX_HS_CPG151101S11_1.5u
M1: SW_Push; SW_MX_HS_CPG151101S11_1u
N1: SW_Push; SW_MX_HS_CPG151101S11_1u
O1: SW_Push; SW_MX_HS_CPG151101S11_1u
OPTION1: SW_Push; SW_MX_HS_CPG151101S11_1.25u
P1: SW_Push; SW_MX_HS_CPG151101S11_1u
PGDN1: SW_Push; SW_MX_HS_CPG151101S11_1u
PGUP1: SW_Push; SW_MX_HS_CPG151101S11_1u
Q1: SW_Push; SW_MX_HS_CPG151101S11_1u
Q2: NMOS; SOT-23_Handsoldering
R1: SW_Push; SW_MX_HS_CPG151101S11_1u
R2, R3: 5.1k; R_0805_2012Metric_Pad1.20x1.40mm_HandSolder
R4, R5, R8: 500Ω; R_0805_2012Metric_Pad1.20x1.40mm_HandSolder
R6: 133Ω; R_0805_2012Metric_Pad1.20x1.40mm_HandSolder
R7: 1000Ω; R_0805_2012Metric_Pad1.20x1.40mm_HandSolder
RIGHTARROW1: SW_Push; SW_MX_HS_CPG151101S11_1u
RIGHTCONTROL1: SW_Push; SW_MX_HS_CPG151101S11_1u
S1: SW_Push; SW_MX_HS_CPG151101S11_1u
SHIFT1: SW_Push; SW_MX_HS_CPG151101S11_1u
SHIFT2: SW_Push; SW_MX_HS_CPG151101S11_1.75u
SPACE1: SW_Push; SW_MX_HS_CPG151101S11_1u
SW0, SW1, SW2, SW3, SW4, SW5, SW6, SW7, SW8, SW9, SW11: SW_Push; SW_MX_HS_CPG151101S11_1u
SW10: RotaryEncoder_Switch_MP; RotaryEncoder_Alps_EC11E-Switch_Vertical_H20mm_MountingHoles
SW_D1: SW_Push; SW_MX_HS_CPG151101S11_1u
T1: SW_Push; SW_MX_HS_CPG151101S11_1u
TAB1: SW_Push; SW_MX_HS_CPG151101S11_1.5u
TP1: TestPoint_D+; TestPoint_Pad_D2.0mm
TP2: TestPoint_D-; TestPoint_Pad_D2.0mm
U4: SW_Push; SW_MX_HS_CPG151101S11_1u
U5: HS096T01H13; LCD-SMD_HS096T01H13; MPN HS096T01H13; LCSC Part C18198246
UPARROW1: SW_Push; SW_MX_HS_CPG151101S11_1u
USB1: TYPEC-306DDW-ARP16; USB-C-TH_TYPEC-306DDW-ARP16; MPN TYPEC-306DDW-ARP16; LCSC Part C2840393
V1: SW_Push; SW_MX_HS_CPG151101S11_1u
W1: SW_Push; SW_MX_HS_CPG151101S11_1u
X1: SW_Push; SW_MX_HS_CPG151101S11_1u
Y1: SW_Push; SW_MX_HS_CPG151101S11_1u
Z1: SW_Push; SW_MX_HS_CPG151101S11_1u
_1: SW_Push; SW_MX_HS_CPG151101S11_1u
{1: SW_Push; SW_MX_HS_CPG151101S11_1u
|1: SW_Push; SW_MX_HS_CPG151101S11_1u
}1: SW_Push; SW_MX_HS_CPG151101S11_1u
~1: SW_Push; SW_MX_HS_CPG151101S11_1u

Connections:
1A: A3.D1 (SWCLK), SW10.A
1B: A3.D3 (SWDIO), SW10.B
1S1: "1.1, +1.1, :1.1, <1.1, >1.1, A1.1, A3.9 (GPIO6), A3.10 (GPIO7), A3.11 (GPIO8), A3.12 (GPIO9), A3.14 (GPIO10), A3.15 (GPIO11), A3.16 (GPIO12), A3.17 (GPIO13), A3.19 (GPIO14), A3.26 (GPIO20), A3.27 (GPIO21), A3.29 (GPIO22), A3.31 (GPIO26_ADC0), B1.1, BACKSPACE1.1, C1.1, CAPSLOCK1.1, COMMANDLEFT1.1, COMMANDRIGHT1.1, D28.1 (K), D31.1 (K), D32.1 (K), D33.1 (K), D34.1 (K), D35.1 (K), D36.1 (K), D37.1 (K), D38.1 (K), D39.1 (K), D40.1 (K), D41.1 (K), D42.1 (K), D44.1 (K), D45.1 (K), D46.1 (K), D47.1 (K), D48.1 (K), D49.1 (K), D50.1 (K), D51.1 (K), D52.1 (K), D53.1 (K), D54.1 (K), D55.1 (K), D56.1 (K), D61.1 (K), D79.1 (K), D83.1 (K), D84.1 (K), D85.1 (K), D86.1 (K), D87.1 (K), D88.1 (K), D89.1 (K), D90.1 (K), DOWNARROW1.1, E1.1, ENTER1.1, ESC1.1, F1.1, F2.1, F3.1, F4.1, F5.1, F6.1, F7.1, F8.1, F9.1, F10.1, F11.1, F12.1, F13.1, FN1.1, G1.1, H1.1, HOME1.1, I1.1, J1.1, K1.1, L1.1, LEFTARROW1.1, LEFTCONTROL1.1, M1.1, N1.1, O1.1, OPTION1.1, P1.1, PGDN1.1, PGUP1.1, Q1.1, R1.1, RIGHTARROW1.1, RIGHTCONTROL1.1, S1.1, SHIFT1.1, SHIFT2.1, SPACE1.1, SW0.1, SW1.1, SW2.1, SW3.1, SW4.1, SW5.1, SW6.1, SW7.1, SW8.1, SW9.1, SW10.S1, SW11.1, SW_D1.1, T1.1, TAB1.1, U4.1, UPARROW1.1, V1.1, W1.1, X1.1, Y1.1, Z1.1, _1.1, {1.1, |1.1, }1.1, ~1.1
2S1: D62.2 (A), SW10.S2
3V3: A3.36 (3V3), U5.10 (VCC)
+5V: A3.40 (VBUS), C_0.1, C_1.1, C_2.1, C_3.1, C_4.1, C_5.1, C_6.1, C_7.1, C_8.1, C_9.1, C_10.1, C_"1.1, C_+1.1, C_:1.1, C_<1.1, C_>1.1, C_A1.1, C_B1.1, C_BACKSPACE1.1, C_C1.1, C_CAPSLOCK1.1, C_D1.1, C_DARRW1.1, C_E1.1, C_ENTER1.1, C_ESC1.1, C_F1.1, C_F2.1, C_F3.1, C_F4.1, C_F5.1, C_F6.1, C_F7.1, C_F8.1, C_F9.1, C_F10.1, C_F11.1, C_F12.1, C_F13.1, C_FN1.1, C_G1.1, C_H1.1, C_HOME1.1, C_I1.1, C_J1.1, C_K1.1, C_L1.1, C_LARRW1.1, C_LCMD1.1, C_LCTRL1.1, C_LFTSHIFT1.1, C_M1.1, C_N1.1, C_O1.1, C_OPTION1.1, C_P1.1, C_PGDN1.1, C_PGUP1.1, C_Q1.1, C_R1.1, C_RARRW1.1, C_RCMD1.1, C_RCTRL1.1, C_R_SHFT1.1, C_S1.1, C_SPACE1.1, C_T1.1, C_TAB1.1, C_U1.1, C_UPARRW1.1, C_V1.1, C_W1.1, C_X1.1, C_Y1.1, C_Z1.1, C__1.1, C_{1.1, C_|1.1, C_}1.1, C_~1.1, LED_0.3 (VDD), LED_1.3 (VDD), LED_2.3 (VDD), LED_3.3 (VDD), LED_4.3 (VDD), LED_5.3 (VDD), LED_6.3 (VDD), LED_7.3 (VDD), LED_8.3 (VDD), LED_9.3 (VDD), LED_10.3 (VDD), LED_"1.3 (VDD), LED_+1.3 (VDD), LED_:1.3 (VDD), LED_<1.3 (VDD), LED_>1.3 (VDD), LED_A1.3 (VDD), LED_B1.3 (VDD), LED_BACKSPACE1.3 (VDD), LED_C1.3 (VDD), LED_CAPSLOCK1.3 (VDD), LED_D1.3 (VDD), LED_D_ARROW1.3 (VDD), LED_E1.3 (VDD), LED_ENTER1.3 (VDD), LED_ESC1.3 (VDD), LED_F1.3 (VDD), LED_F2.3 (VDD), LED_F3.3 (VDD), LED_F4.3 (VDD), LED_F5.3 (VDD), LED_F6.3 (VDD), LED_F7.3 (VDD), LED_F8.3 (VDD), LED_F9.3 (VDD), LED_F10.3 (VDD), LED_F11.3 (VDD), LED_F12.3 (VDD), LED_F13.3 (VDD), LED_FN1.3 (VDD), LED_G1.3 (VDD), LED_H1.3 (VDD), LED_HOME1.3 (VDD), LED_I1.3 (VDD), LED_J1.3 (VDD), LED_K1.3 (VDD), LED_L1.3 (VDD), LED_LEFTSHIFT1.3 (VDD), LED_L_ARROW1.3 (VDD), LED_L_CMD1.3 (VDD), LED_L_CTRL1.3 (VDD), LED_M1.3 (VDD), LED_N1.3 (VDD), LED_O1.3 (VDD), LED_OPTION1.3 (VDD), LED_P1.3 (VDD), LED_PGDN1.3 (VDD), LED_PGUP1.3 (VDD), LED_Q1.3 (VDD), LED_R1.3 (VDD)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
D+: TP1.1 (1_1), USB1.A6 (DP1), USB1.B6 (DP2)
D-: TP2.1 (1_1), USB1.A7 (DN1), USB1.B7 (DN2)
GND: A3.3 (GND), A3.8 (GND), A3.13 (GND), A3.18 (GND), A3.23 (GND), A3.28 (GND), A3.38 (GND), A3.D2 (GND), C_0.2, C_1.2, C_2.2, C_3.2, C_4.2, C_5.2, C_6.2, C_7.2, C_8.2, C_9.2, C_10.2, C_"1.2, C_+1.2, C_:1.2, C_<1.2, C_>1.2, C_A1.2, C_B1.2, C_BACKSPACE1.2, C_C1.2, C_CAPSLOCK1.2, C_D1.2, C_DARRW1.2, C_E1.2, C_ENTER1.2, C_ESC1.2, C_F1.2, C_F2.2, C_F3.2, C_F4.2, C_F5.2, C_F6.2, C_F7.2, C_F8.2, C_F9.2, C_F10.2, C_F11.2, C_F12.2, C_F13.2, C_FN1.2, C_G1.2, C_H1.2, C_HOME1.2, C_I1.2, C_J1.2, C_K1.2, C_L1.2, C_LARRW1.2, C_LCMD1.2, C_LCTRL1.2, C_LFTSHIFT1.2, C_M1.2, C_N1.2, C_O1.2, C_OPTION1.2, C_P1.2, C_PGDN1.2, C_PGUP1.2, C_Q1.2, C_R1.2, C_RARRW1.2, C_RCMD1.2, C_RCTRL1.2, C_R_SHFT1.2, C_S1.2, C_SPACE1.2, C_T1.2, C_TAB1.2, C_U1.2, C_UPARRW1.2, C_V1.2, C_W1.2, C_X1.2, C_Y1.2, C_Z1.2, C__1.2, C_{1.2, C_|1.2, C_}1.2, C_~1.2, D63.1 (K), LED_0.1 (VSS), LED_1.1 (VSS), LED_2.1 (VSS), LED_3.1 (VSS), LED_4.1 (VSS), LED_5.1 (VSS), LED_6.1 (VSS), LED_7.1 (VSS), LED_8.1 (VSS), LED_9.1 (VSS), LED_10.1 (VSS), LED_"1.1 (VSS), LED_+1.1 (VSS), LED_:1.1 (VSS), LED_<1.1 (VSS), LED_>1.1 (VSS), LED_A1.1 (VSS), LED_B1.1 (VSS), LED_BACKSPACE1.1 (VSS), LED_C1.1 (VSS), LED_CAPSLOCK1.1 (VSS), LED_D1.1 (VSS), LED_D_ARROW1.1 (VSS), LED_E1.1 (VSS), LED_ENTER1.1 (VSS), LED_ESC1.1 (VSS), LED_F1.1 (VSS), LED_F2.1 (VSS), LED_F3.1 (VSS), LED_F4.1 (VSS), LED_F5.1 (VSS), LED_F6.1 (VSS), LED_F7.1 (VSS), LED_F8.1 (VSS), LED_F9.1 (VSS), LED_F10.1 (VSS), LED_F11.1 (VSS), LED_F12.1 (VSS), LED_F13.1 (VSS), LED_FN1.1 (VSS), LED_G1.1 (VSS), LED_H1.1 (VSS), LED_HOME1.1 (VSS), LED_I1.1 (VSS), LED_J1.1 (VSS), LED_K1.1 (VSS), LED_L1.1 (VSS), LED_LEFTSHIFT1.1 (VSS), LED_L_ARROW1.1 (VSS), LED_L_CMD1.1 (VSS), LED_L_CTRL1.1 (VSS), LED_M1.1 (VSS)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
LCD_CLK: A3.4 (GPIO2), U5.4 (SCL)
LCD_CS: A3.7 (GPIO5), U5.7 (CS)
LCD_DC: A3.2 (GPIO1), U5.5 (RS)
LCD_MOSI: A3.5 (GPIO3), U5.3 (SDA)
LCD_RES: A3.1 (GPIO0), U5.6 (RES)
LED DIN: A3.32 (GPIO27_ADC1), R4.1
NMOS_DRAIN: Q2.1 (D), U5.11 (LEDK)
NMOS_GATE: A3.6 (GPIO4), R7.2
unnamed: D1.2 (A), SW1.2
unnamed: D2.2 (A), SW2.2
unnamed: D3.2 (A), SW3.2
unnamed: D4.2 (A), SW4.2
unnamed: D5.2 (A), SW5.2
unnamed: D6.2 (A), SW6.2
unnamed: D7.2 (A), SW7.2
unnamed: D8.2 (A), SW8.2
unnamed: D9.2 (A), SW9.2
unnamed: D10.2 (A), SW0.2
unnamed: D11.2 (A), _1.2
unnamed: +1.2, D12.2 (A)
unnamed: BACKSPACE1.2, D13.2 (A)
unnamed: D14.2 (A), PGUP1.2
unnamed: D15.2 (A), Q1.2
unnamed: D16.2 (A), W1.2
unnamed: D17.2 (A), E1.2
unnamed: D18.2 (A), R1.2
unnamed: D19.2 (A), T1.2
unnamed: D20.2 (A), Y1.2
unnamed: D21.2 (A), U4.2
unnamed: D22.2 (A), I1.2
unnamed: D23.2 (A), O1.2
unnamed: D24.2 (A), P1.2
unnamed: D25.2 (A), {1.2
unnamed: D26.2 (A), }1.2
unnamed: D27.2 (A), |1.2
unnamed: D28.2 (A), PGDN1.2
unnamed: CAPSLOCK1.2, D29.2 (A)
unnamed: A1.2, D30.2 (A)
unnamed: D31.2 (A), S1.2
unnamed: D32.2 (A), SW_D1.2
unnamed: D33.2 (A), F13.2
unnamed: D34.2 (A), G1.2
unnamed: D35.2 (A), H1.2
unnamed: D36.2 (A), J1.2
unnamed: D37.2 (A), K1.2
unnamed: D38.2 (A), L1.2
unnamed: :1.2, D39.2 (A)
unnamed: "1.2, D40.2 (A)
unnamed: D41.2 (A), ENTER1.2
unnamed: D42.2 (A), HOME1.2
unnamed: D43.2 (A), F1.2
unnamed: D44.2 (A), SHIFT1.2
unnamed: D45.2 (A), Z1.2
unnamed: D46.2 (A), X1.2
unnamed: C1.2, D47.2 (A)
unnamed: D48.2 (A), V1.2
unnamed: B1.2, D49.2 (A)
unnamed: D50.2 (A), N1.2
unnamed: D51.2 (A), M1.2
unnamed: <1.2, D52.2 (A)
unnamed: >1.2, D53.2 (A)
unnamed: D54.2 (A), SW11.2
unnamed: D55.2 (A), SHIFT2.2
unnamed: D56.2 (A), UPARROW1.2
unnamed: D57.2 (A), F2.2
unnamed: D58.2 (A), F3.2
unnamed: D59.2 (A), F4.2
unnamed: D60.2 (A), F5.2
unnamed: D61.2 (A), LEFTCONTROL1.2
unnamed: D63.2 (A), R8.2
unnamed: D71.2 (A), F6.2
unnamed: D72.2 (A), F7.2
unnamed: D73.2 (A), F8.2
unnamed: D74.2 (A), F9.2
unnamed: D75.2 (A), F10.2
unnamed: D76.2 (A), F11.2
unnamed: D77.2 (A), F12.2
unnamed: D79.2 (A), OPTION1.2
unnamed: D80.2 (A), ESC1.2
unnamed: D81.2 (A), ~1.2
unnamed: D82.2 (A), TAB1.2
unnamed: COMMANDLEFT1.2, D83.2 (A)
unnamed: D84.2 (A), SPACE1.2
unnamed: COMMANDRIGHT1.2, D85.2 (A)
unnamed: D86.2 (A), FN1.2
unnamed: D87.2 (A), RIGHTCONTROL1.2
unnamed: D88.2 (A), LEFTARROW1.2
unnamed: D89.2 (A), DOWNARROW1.2
unnamed: D90.2 (A), RIGHTARROW1.2
unnamed: LED_0.2 (DIN), LED__1.4 (DOUT)
unnamed: LED_0.4 (DOUT), LED_9.2 (DIN)
unnamed: LED_1.2 (DIN), LED_2.4 (DOUT)
unnamed: LED_1.4 (DOUT), LED_~1.2 (DIN)
unnamed: LED_2.2 (DIN), LED_3.4 (DOUT)
unnamed: LED_3.2 (DIN), LED_4.4 (DOUT)
unnamed: LED_4.2 (DIN), LED_5.4 (DOUT)
unnamed: LED_5.2 (DIN), LED_6.4 (DOUT)
unnamed: LED_6.2 (DIN), LED_7.4 (DOUT)
unnamed: LED_7.2 (DIN), LED_8.4 (DOUT)
unnamed: LED_8.2 (DIN), LED_9.4 (DOUT)
unnamed: LED_10.2 (DIN), LED_>1.4 (DOUT)
unnamed: LED_10.4 (DOUT), LED_R_SHIFT1.2 (DIN)
unnamed: LED_"1.2 (DIN), LED_ENTER1.4 (DOUT)
unnamed: LED_"1.4 (DOUT), LED_:1.2 (DIN)
unnamed: LED_+1.2 (DIN), LED_BACKSPACE1.4 (DOUT)
unnamed: LED_+1.4 (DOUT), LED__1.2 (DIN)
unnamed: LED_:1.4 (DOUT), LED_L1.2 (DIN)
unnamed: LED_<1.2 (DIN), LED_M1.4 (DOUT)
unnamed: LED_<1.4 (DOUT), LED_>1.2 (DIN)
unnamed: LED_A1.2 (DIN), LED_S1.4 (DOUT)
unnamed: LED_A1.4 (DOUT), LED_CAPSLOCK1.2 (DIN)
unnamed: LED_B1.2 (DIN), LED_V1.4 (DOUT)
unnamed: LED_B1.4 (DOUT), LED_N1.2 (DIN)
unnamed: LED_BACKSPACE1.2 (DIN), LED_F12.4 (DOUT)
unnamed: LED_C1.2 (DIN), LED_X1.4 (DOUT)
unnamed: LED_C1.4 (DOUT), LED_V1.2 (DIN)
unnamed: LED_CAPSLOCK1.4 (DOUT), LED_LEFTSHIFT1.2 (DIN)
unnamed: LED_D1.2 (DIN), LED_F13.4 (DOUT)
unnamed: LED_D1.4 (DOUT), LED_S1.2 (DIN)
unnamed: LED_D_ARROW1.2 (DIN), LED_R_ARROW1.4 (DOUT)
unnamed: LED_D_ARROW1.4 (DOUT), LED_L_ARROW1.2 (DIN)
unnamed: LED_E1.2 (DIN), LED_W1.4 (DOUT)
unnamed: LED_E1.4 (DOUT), LED_R1.2 (DIN)
unnamed: LED_ENTER1.2 (DIN), LED_PGDN1.4 (DOUT)
unnamed: LED_ESC1.2 (DIN), R4.2
unnamed: LED_ESC1.4 (DOUT), LED_F1.2 (DIN)
unnamed: LED_F1.4 (DOUT), LED_F2.2 (DIN)
unnamed: LED_F2.4 (DOUT), LED_F3.2 (DIN)
unnamed: LED_F3.4 (DOUT), LED_F4.2 (DIN)
unnamed: LED_F4.4 (DOUT), LED_F5.2 (DIN)
unnamed: LED_F5.4 (DOUT), LED_F6.2 (DIN)
unnamed: LED_F6.4 (DOUT), LED_F7.2 (DIN)
unnamed: LED_F7.4 (DOUT), LED_F8.2 (DIN)
unnamed: LED_F8.4 (DOUT), LED_F9.2 (DIN)
unnamed: LED_F9.4 (DOUT), LED_F10.2 (DIN)
unnamed: LED_F10.4 (DOUT), LED_F11.2 (DIN)
unnamed: LED_F11.4 (DOUT), LED_F12.2 (DIN)
unnamed: LED_F13.2 (DIN), LED_G1.4 (DOUT)
unnamed: LED_FN1.2 (DIN), LED_R_CTRL1.4 (DOUT)
unnamed: LED_FN1.4 (DOUT), LED_R_CMD1.2 (DIN)
unnamed: LED_G1.2 (DIN), LED_H1.4 (DOUT)
unnamed: LED_H1.2 (DIN), LED_J1.4 (DOUT)
unnamed: LED_HOME1.2 (DIN), LED_UPARROW1.4 (DOUT)
unnamed: LED_HOME1.4 (DOUT), LED_R_ARROW1.2 (DIN)
unnamed: LED_I1.2 (DIN), LED_U1.4 (DOUT)
unnamed: LED_I1.4 (DOUT), LED_O1.2 (DIN)
unnamed: LED_J1.2 (DIN), LED_K1.4 (DOUT)
unnamed: LED_K1.2 (DIN), LED_L1.4 (DOUT)
unnamed: LED_LEFTSHIFT1.4 (DOUT), LED_Z1.2 (DIN)
unnamed: LED_L_ARROW1.4 (DOUT), LED_R_CTRL1.2 (DIN)
unnamed: LED_L_CMD1.2 (DIN), LED_SPACE1.4 (DOUT)
unnamed: LED_L_CMD1.4 (DOUT), LED_OPTION1.2 (DIN)
unnamed: LED_L_CTRL1.2 (DIN), LED_OPTION1.4 (DOUT)
unnamed: LED_L_CTRL1.4 (DOUT), R5.2
unnamed: LED_M1.2 (DIN), LED_N1.4 (DOUT)
unnamed: LED_O1.4 (DOUT), LED_P1.2 (DIN)
unnamed: LED_P1.4 (DOUT), LED_{1.2 (DIN)
unnamed: LED_PGDN1.2 (DIN), LED_PGUP1.4 (DOUT)
unnamed: LED_PGUP1.2 (DIN), LED_|1.4 (DOUT)
unnamed: LED_Q1.2 (DIN), LED_TAB1.4 (DOUT)
unnamed: LED_Q1.4 (DOUT), LED_W1.2 (DIN)
unnamed: LED_R1.4 (DOUT), LED_T1.2 (DIN)
unnamed: LED_R_CMD1.4 (DOUT), LED_SPACE1.2 (DIN)
unnamed: LED_R_SHIFT1.4 (DOUT), LED_UPARROW1.2 (DIN)
unnamed: LED_T1.4 (DOUT), LED_Y1.2 (DIN)
unnamed: LED_TAB1.2 (DIN), LED_~1.4 (DOUT)
unnamed: LED_U1.2 (DIN), LED_Y1.4 (DOUT)
unnamed: LED_X1.2 (DIN), LED_Z1.4 (DOUT)
unnamed: LED_{1.4 (DOUT), LED_}1.2 (DIN)
unnamed: LED_|1.2 (DIN), LED_}1.4 (DOUT)
unnamed: Q2.2 (G), R7.1
unnamed: R6.2, U5.12 (LEDA)
unnamed: R3.2, USB1.A5 (CC1)
unnamed: R2.1, USB1.B5 (CC2)
ROW0: A3.20 (GPIO15), D43.1 (K), D57.1 (K), D58.1 (K), D59.1 (K), D60.1 (K), D71.1 (K), D72.1 (K), D73.1 (K), D80.1 (K)
ROW1: A3.21 (GPIO16), D1.1 (K), D2.1 (K), D3.1 (K), D4.1 (K), D74.1 (K), D75.1 (K), D76.1 (K), D77.1 (K), D81.1 (K)
ROW2: A3.22 (GPIO17), D5.1 (K), D6.1 (K), D7.1 (K), D8.1 (K), D9.1 (K), D10.1 (K), D11.1 (K), D12.1 (K), D13.1 (K)
ROW3: A3.24 (GPIO18), D15.1 (K), D16.1 (K), D17.1 (K), D18.1 (K), D19.1 (K), D20.1 (K), D21.1 (K), D62.1 (K), D82.1 (K)
ROW4: A3.25 (GPIO19), D14.1 (K), D22.1 (K), D23.1 (K), D24.1 (K), D25.1 (K), D26.1 (K), D27.1 (K), D29.1 (K), D30.1 (K)

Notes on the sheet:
Keyboard Matrix
Testpoints
NMos Transistor
Raspberry Pi Pico
USBC
Power
ST7735 LCD
Backlight LEDs
Rotary Encoder

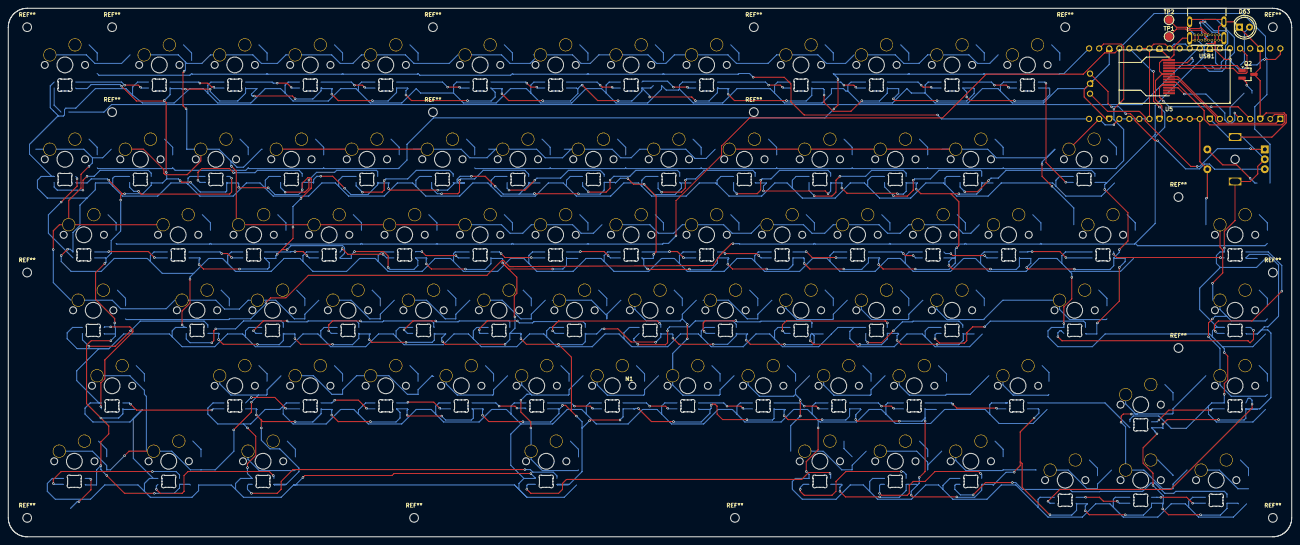
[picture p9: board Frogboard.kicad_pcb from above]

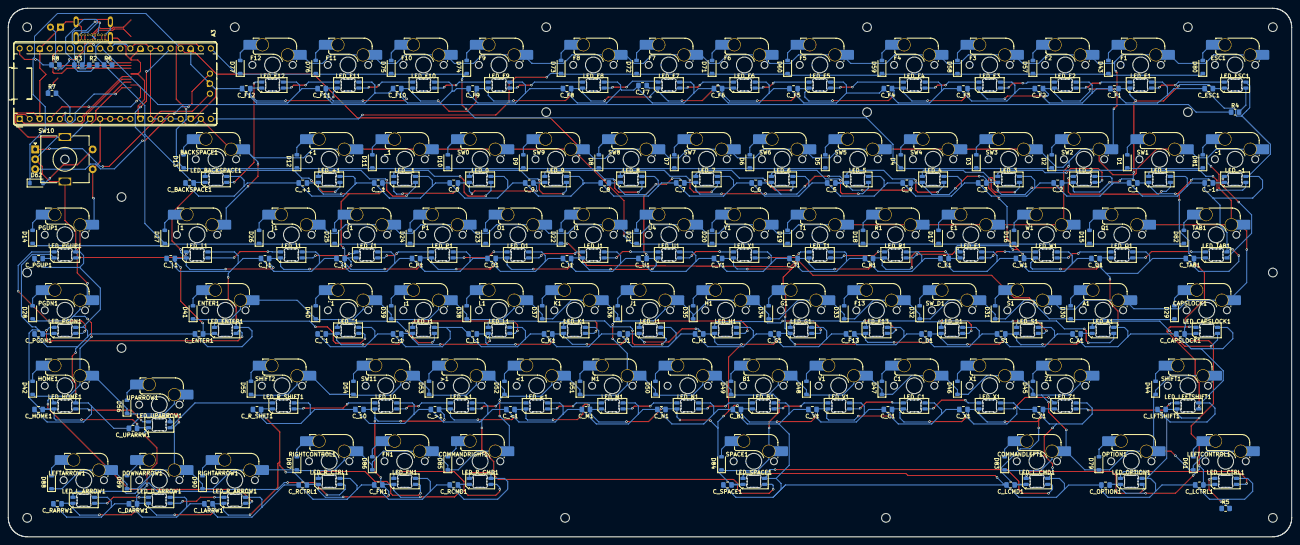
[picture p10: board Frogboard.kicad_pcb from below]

Board: 2 copper layers, 323.9 x 133.4 mm, 335 parts (329 on the bottom side), 187 nets.

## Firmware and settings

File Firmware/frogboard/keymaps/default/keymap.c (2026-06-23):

// Copyright 2023 QMK
// SPDX-License-Identifier: GPL-2.0-or-later

#include QMK_KEYBOARD_H
#include <qp.h>

enum layer_names{
    _DEFAULT = 0,
    _FUNCTION,
};

const uint16_t PROGMEM keymaps[][MATRIX_ROWS][MATRIX_COLS] = {

    [_DEFAULT] = LAYOUT_75_ansi(
        KC_ESC, KC_F1, KC_F2, KC_F3, KC_F4, KC_F5, KC_F6, KC_F7, KC_F8, KC_F9, KC_F10, KC_F11, KC_F12,
        KC_GRV, KC_1, KC_2, KC_3, KC_4, KC_5, KC_6, KC_7, KC_8, KC_9, KC_0, KC_MINS, KC_EQL, KC_BSPC, KC_NO,
        KC_TAB, KC_Q, KC_W, KC_E, KC_R, KC_T, KC_Y, KC_U, KC_I, KC_O, KC_P, KC_LBRC, KC_RBRC, KC_BSLS, KC_PGUP,
        KC_CAPS, KC_A, KC_S, KC_D, KC_F, KC_G, KC_H, KC_J, KC_K, KC_L, KC_SCLN, KC_QUOT, KC_ENT, KC_PGDN,
        KC_LSFT, KC_Z, KC_X, KC_C, KC_V, KC_B, KC_N, KC_M, KC_COMM, KC_DOT,  KC_SLSH, KC_RSFT, KC_UP, KC_DEL
        KC_LCTL, KC_LGUI, KC_LALT, KC_SPC, KC_RALT, MO(_FUNCTION), KC_RCTL, KC_LEFT, KC_DOWN, KC_RGHT
    ),

    [_FUNCTION] = LAYOUT_75_ansi(
        KC_TRNS, KC_F1, KC_F2, KC_F3, KC_F4, KC_F5, KC_F6, KC_F7, KC_F8, KC_F9, KC_F10, KC_F11, KC_F12,  
        KC_TRNS, KC_TRNS, KC_TRNS, KC_TRNS, KC_TRNS, KC_TRNS, KC_TRNS, KC_TRNS, KC_TRNS, KC_TRNS, KC_TRNS, KC_TRNS, KC_TRNS, KC_TRNS, KC_TRNS,
        KC_TRNS, KC_TRNS, KC_TRNS, KC_TRNS, KC_TRNS, KC_TRNS, KC_TRNS, KC_TRNS, KC_TRNS, KC_TRNS, KC_TRNS, KC_TRNS, KC_TRNS, KC_TRNS, KC_TRNS,
        KC_TRNS, KC_TRNS, KC_TRNS, KC_TRNS, KC_TRNS, KC_TRNS, KC_TRNS, KC_TRNS, KC_TRNS, KC_TRNS, KC_TRNS, KC_TRNS, KC_TRNS, KC_TRNS,
        KC_TRNS, KC_TRNS, KC_TRNS, KC_TRNS, KC_TRNS, KC_TRNS, KC_TRNS, KC_TRNS, KC_TRNS, KC_TRNS,  KC_TRNS, KC_TRNS, KC_TRNS, KC_TRNS,
        KC_TRNS, KC_TRNS, KC_TRNS, KC_TRNS, KC_TRNS, KC_TRNS, KC_TRNS, KC_TRNS, KC_TRNS, KC_TRNS
    ),

};

#if defined(ENCODER_MAP_ENABLE)

const uint16_t PROGMEM encoder_map[][1][2] = {
    [_DEFAULT] = {ENCODER_CCW_CW(KC_VOLD, KC_VOLU)},
    [_FUNCTION] = {ENCODER_CCW_CW(KC_VOLD, KC_VOLU)},
};

#endif

#if defined(QUANTUM_PAINTER_ENABLE)



static painter_device_t display;
void keyboard_post_init_kb(void){
    display = qp_st7735_make_spi_device {
            uint16_t 160, 
            uint16_t 80, 
            pin_t GP5, 
            pin_t GP1, 
            pin_t GP0, 
            uint16_t 4, 
            int 0,
    };
    qp_init(display, QP_ROTATION_0);
};

void housekeeping_task_user(void) {
    static uint32_t last_draw = 0;
    if(timer_elapsed32(last_draw) > 33) {
        last_draw = timer_read32();
        qp_setpixel(display, 37, 80, 0, 255, 255);// draws a . - . face in the middle of the screen
        qp_setpixel(display, 39, 80, 0, 255, 255);
        qp_setpixel(display, 40, 80, 0, 255, 255);
        qp_setpixel(display, 42, 80, 0, 255, 255);
        qp_flush(display);



    }
}

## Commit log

2026-06-20 Upload CAD files
    [Base.f3d, Base.step, Encoder cap.step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]
2026-06-20 Reupload pcb
    [Frogboard.kicad_pcb, Frogboard.kicad_sch]
2026-06-21 Added source files
    [BOM.csv]
2026-06-21 Update BOM
    [BOM.csv]
2026-06-21 Revise BOM table format and add items
    Updated the Bill of Materials (BOM) table format for better readability and added missing items.
2026-06-21 Fix switch plate files
    [Plate.f3d, Plate.step]
2026-06-22 Fixing the PCB files
    [Frogboard.kicad_pcb, Frogboard.kicad_sch]
2026-06-22 Fixed the CAD files
    [Base.f3d, Base.step, Encoder cap.step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]
2026-06-22 Organized Files
    [Base.step, Rotary Encoder Cap.step, Switch Plate Assembled.f3z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]
2026-06-22 Revise assembly instructions and add images
    Updated assembly instructions for clarity and added images.
2026-06-22 Update instructions for attaching the top plate
    Removed mention of using glue and magnets for the top plate attachment.
2026-06-22 added top p late to the cad
    [Top Plate.f3d, Top Plate.step]
2026-06-23 Added more spi stuff to the code
2026-06-23 Update PCB
    [Frogboard.kicad_pcb]
2026-06-26 Update total cost and add jumper wires to README
